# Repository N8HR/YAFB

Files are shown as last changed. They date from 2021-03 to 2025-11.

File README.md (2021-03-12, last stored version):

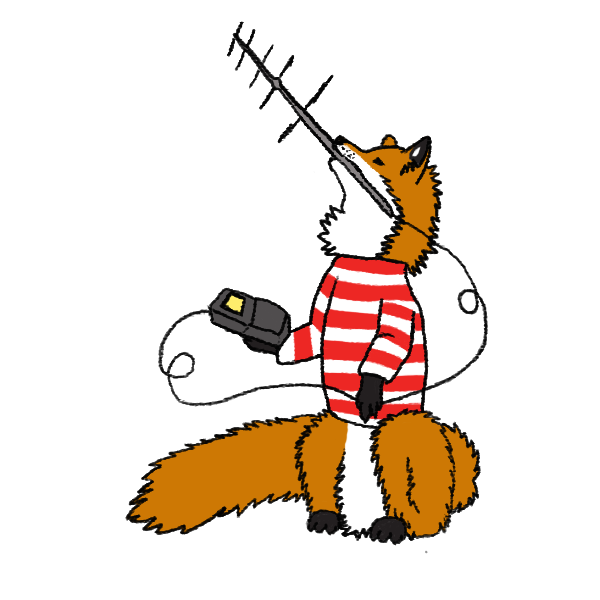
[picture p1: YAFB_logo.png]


# Yet Another Foxbox (YAFB)
YAFB is an amateur radio fox transmitter designed for an ESP32-S2-Saola-1 and a NiceRF SA818.

Still being worked on and is not in a functional state but there is a cool logo to look at!

My goal is to provide a way to make a cheap alternative fox transmitter. When done you'll be provided with all the files needed to make your own.

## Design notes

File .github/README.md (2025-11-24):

> [!Note]
> This is a project that doesn't get enough of my time and is never complete.  
> If you want an actual product that just works and is based off of this project, see https://github.com/c0ldbru/fox

# Yet Another Foxbox (YAFB)



YAFB is an amateur radio fox transmitter designed for an ESP32-S2-Saola-1 and a NiceRF SA818.

Still being worked on and now works fairly well on my bench. Hasn't been tested yet in the field.
As of Nov 2023 just sent in to have v4.1 of the board to be made. More updates soon.

I started this because I was too cheap to buy one and I had way too much time on my hands. And I kind of am enjoying it. Weird. 

My goal is to provide a way to make a cheap alternative fox transmitter. When done you'll be provided with all the files needed to make your own.

## Features
* 1W VHF or UHF transmitter (NiceRF SA818)
* Configure it over Bluetooth

## PCB
|Front|Back|
|:-:|:-:|
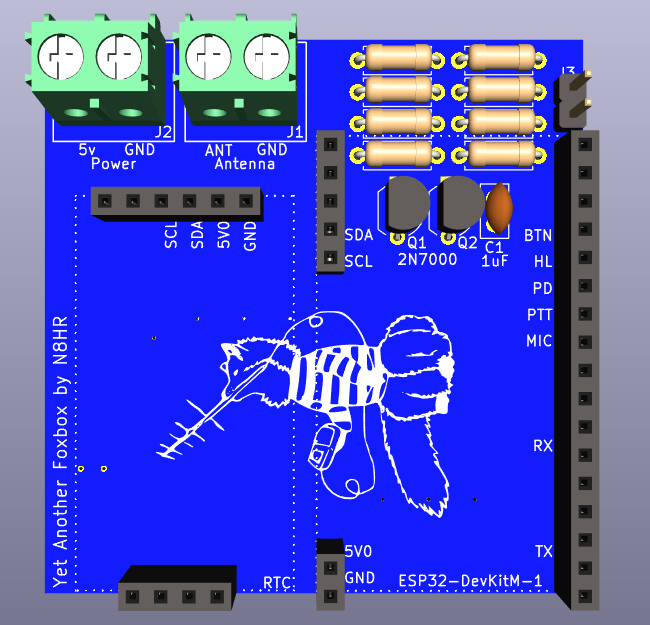
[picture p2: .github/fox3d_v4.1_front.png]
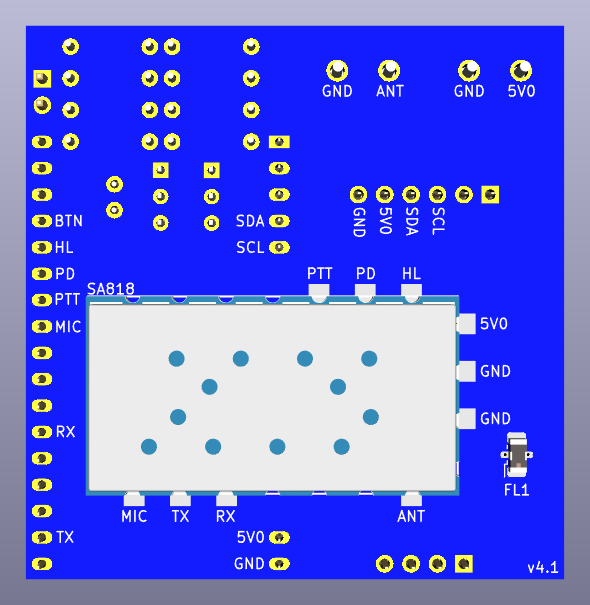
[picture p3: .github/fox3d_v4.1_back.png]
|||

## Parts
* 1x ESP32-S2-Saola-1R Dev Board (Microcontroller)
* 1x NiceRF SA818(S) (Transmitter)
* 1x DS3231 RTC Module (Real Time Clock)
* 1x Mini-Circuits LFCN-160+ (Low Pass Filter)
* 3x 10k Resistors
* 1x 3.3k Resistor
* 1x 1.8k Resistor
* 1x 1k Resistor
* 2x 150 Resistor
* 1x 1uF Capacitor
* 2x 2N7000 Transistor
* 2x TB002-500-02BE Terminal Blocks
* Male and Female Header Connectors
* 5v Power Source
* Optional Push Button

## Licenses
* The hardware side of this project uses the CERN Open Hardware Licence Version 2 - Weakly Reciprocal (CERN-OHL-W-2.0)
* The software side of this project uses the GNU General Public License v3.0 or later (GPL-3.0-or-later)

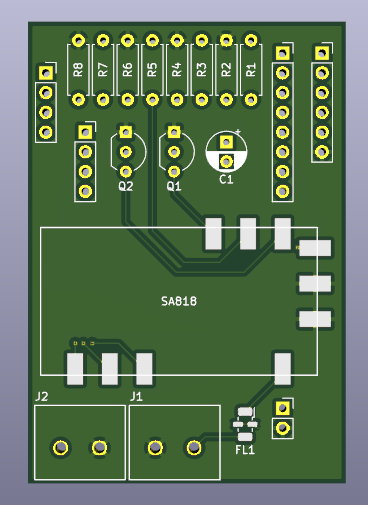
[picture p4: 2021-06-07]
.github/fox3d_front.png

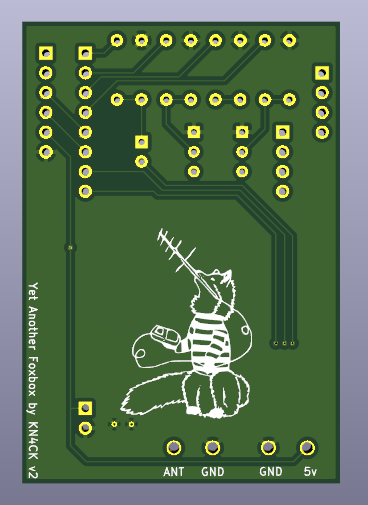
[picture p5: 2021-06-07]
.github/fox3d_back.png

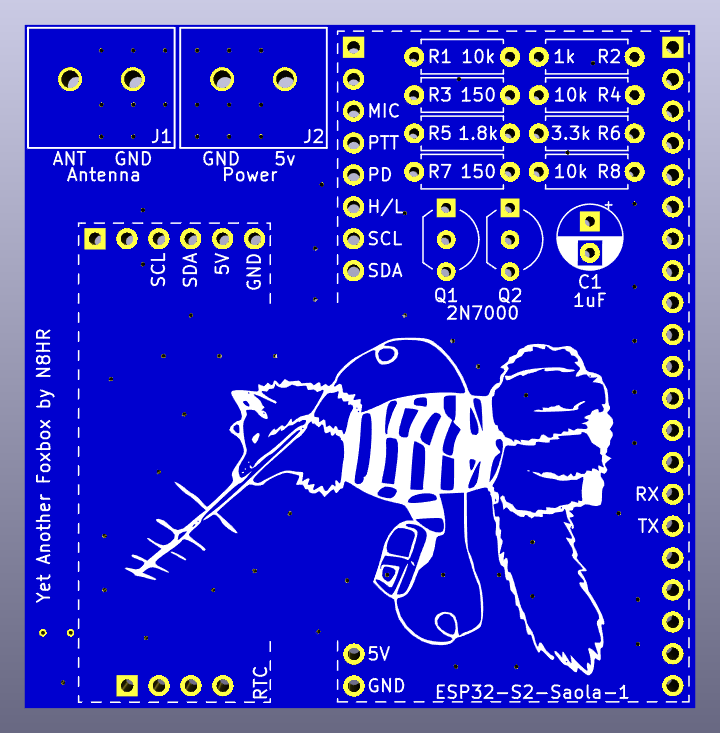
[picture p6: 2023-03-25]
.github/fox3d_v3_front.png

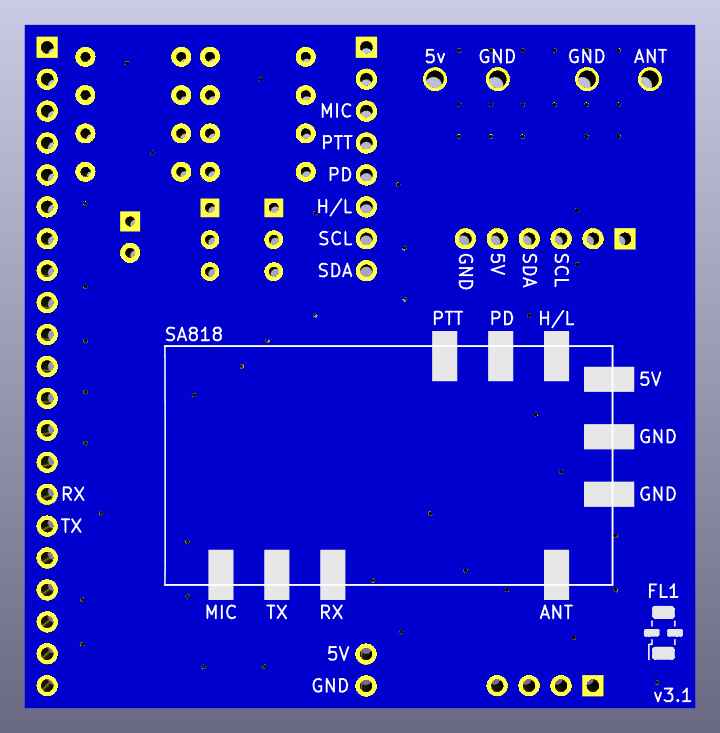
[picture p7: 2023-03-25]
.github/fox3d_v3_back.png

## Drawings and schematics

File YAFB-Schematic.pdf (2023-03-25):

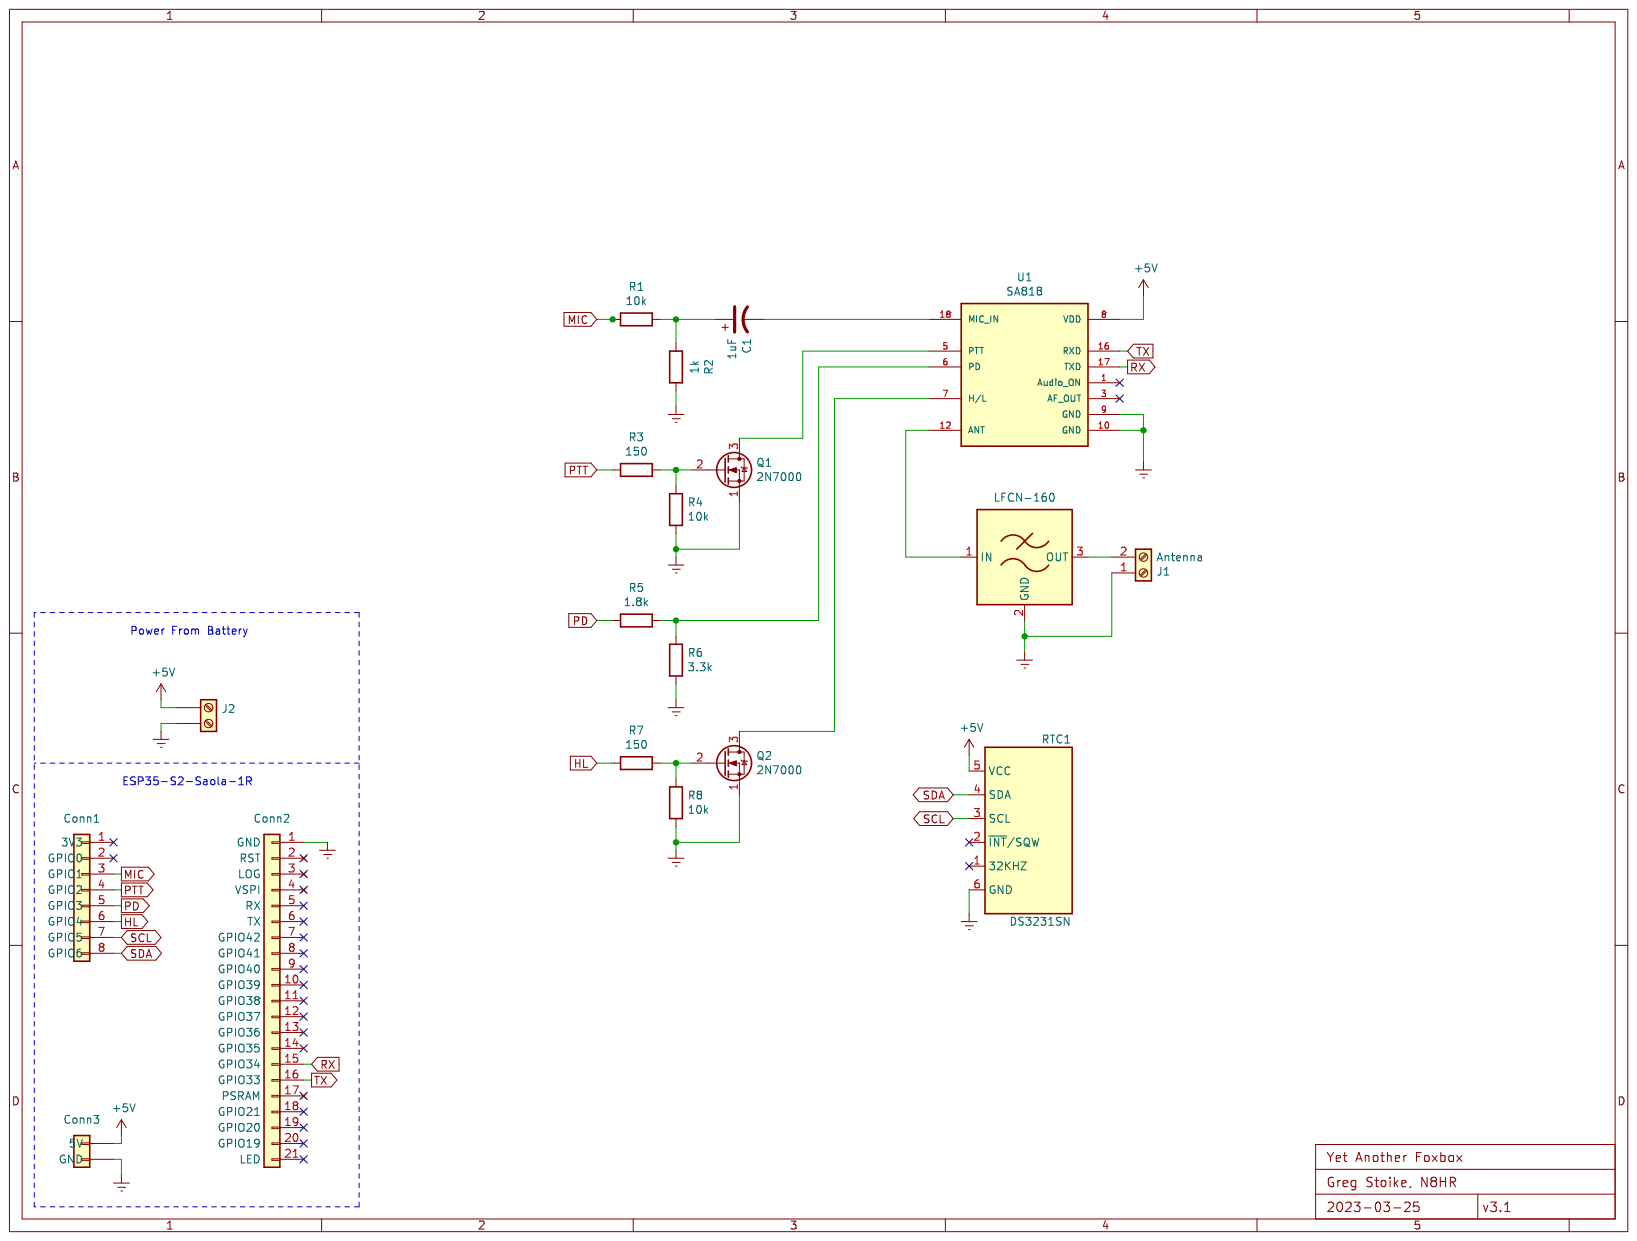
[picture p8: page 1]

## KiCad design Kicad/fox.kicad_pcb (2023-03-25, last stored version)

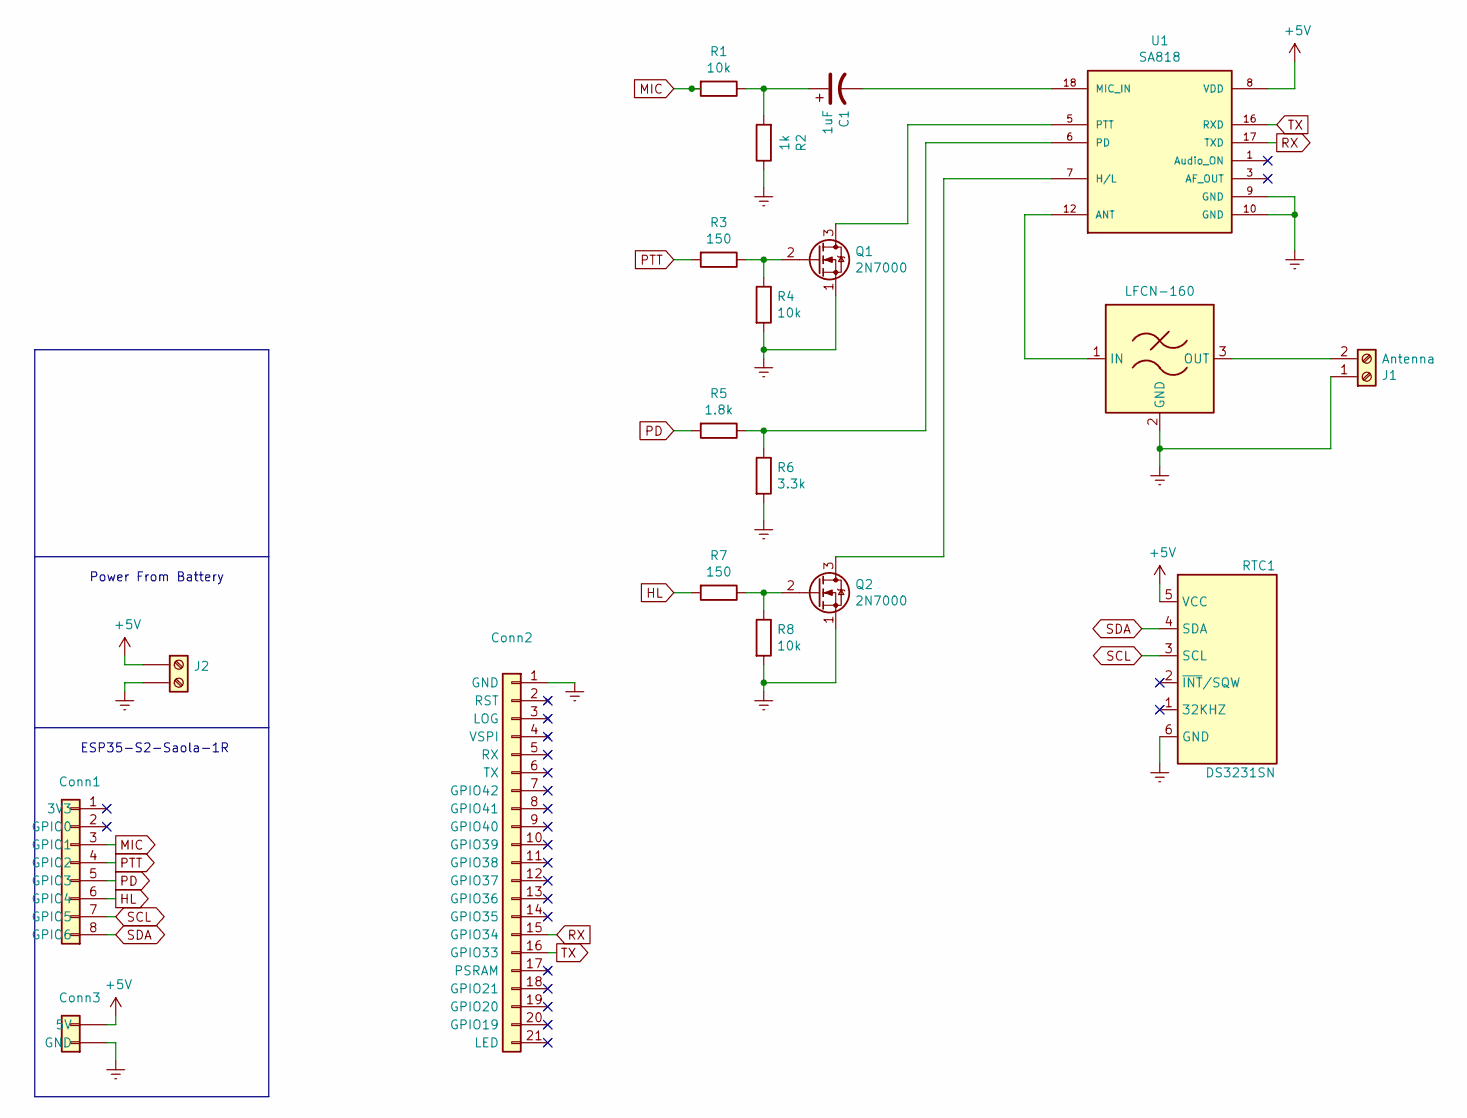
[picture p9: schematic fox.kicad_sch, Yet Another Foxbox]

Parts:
C1: 1uF; CP_Radial_D5.0mm_P2.50mm
Conn1: ESP32-S2-Saola-1R_GPIO_1; PinSocket_1x08_P2.54mm_Vertical
Conn2: ESP32-S2-Saola-1R_GPIO_2; PinSocket_1x21_P2.54mm_Vertical
Conn3: ESP32-S2-Saola-1R_Power; PinSocket_1x02_P2.54mm_Vertical
FL1: LFCN-160; Filter_Mini-Circuits_FV1206
J1: Antenna; OSTTA020161
J2: Power; OSTTA020161
Q1, Q2: 2N7000; TO-92_Inline_Wide
R1, R4, R8: 10k; R_Axial_DIN0207_L6.3mm_D2.5mm_P7.62mm_Horizontal
R2: 1k; R_Axial_DIN0207_L6.3mm_D2.5mm_P7.62mm_Horizontal
R3, R7: 150; R_Axial_DIN0207_L6.3mm_D2.5mm_P7.62mm_Horizontal
R5: 1.8k; R_Axial_DIN0207_L6.3mm_D2.5mm_P7.62mm_Horizontal
R6: 3.3k; R_Axial_DIN0207_L6.3mm_D2.5mm_P7.62mm_Horizontal
RTC1: DS3231SN
U1: SA818; DRA818; PART_REV 1.23

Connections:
+5V: Conn3.5v0 (5V), J2.1, RTC1.5 (VCC), U1.8 (VDD)
GNDREF: Conn2.1 (GND), Conn3.GND, FL1.2 (GND), FL1.4 (GND), J1.1, J2.2, Q1.1 (S), Q2.1 (S), R2.1, R4.2, R6.2, R8.2, RTC1.6 (GND), U1.9 (GND), U1.10 (GND)
HL: Conn1.6 (GPIO4), R7.2
MIC: Conn1.3 (GPIO1), R1.2
unnamed: C1.1, R1.1, R2.2
unnamed: C1.2, U1.18 (MIC_IN)
unnamed: FL1.1 (IN), U1.12 (ANT)
unnamed: FL1.3 (OUT), J1.2
unnamed: Q1.2 (G), R3.1, R4.1
unnamed: Q1.3 (D), U1.5 (PTT)
unnamed: Q2.2 (G), R7.1, R8.1
unnamed: Q2.3 (D), U1.7 (H/L)
unnamed: R5.1, R6.1, U1.6 (PD)
PD: Conn1.5 (GPIO3), R5.2
PTT: Conn1.4 (GPIO2), R3.2
RX: Conn2.15 (GPIO34), U1.17 (TXD)
SCL: Conn1.7 (GPIO5), RTC1.3 (SCL)
SDA: Conn1.8 (GPIO6), RTC1.4 (SDA)
TX: Conn2.16 (GPIO33), U1.16 (RXD)

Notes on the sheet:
ESP35-S2-Saola-1R
Power From Battery

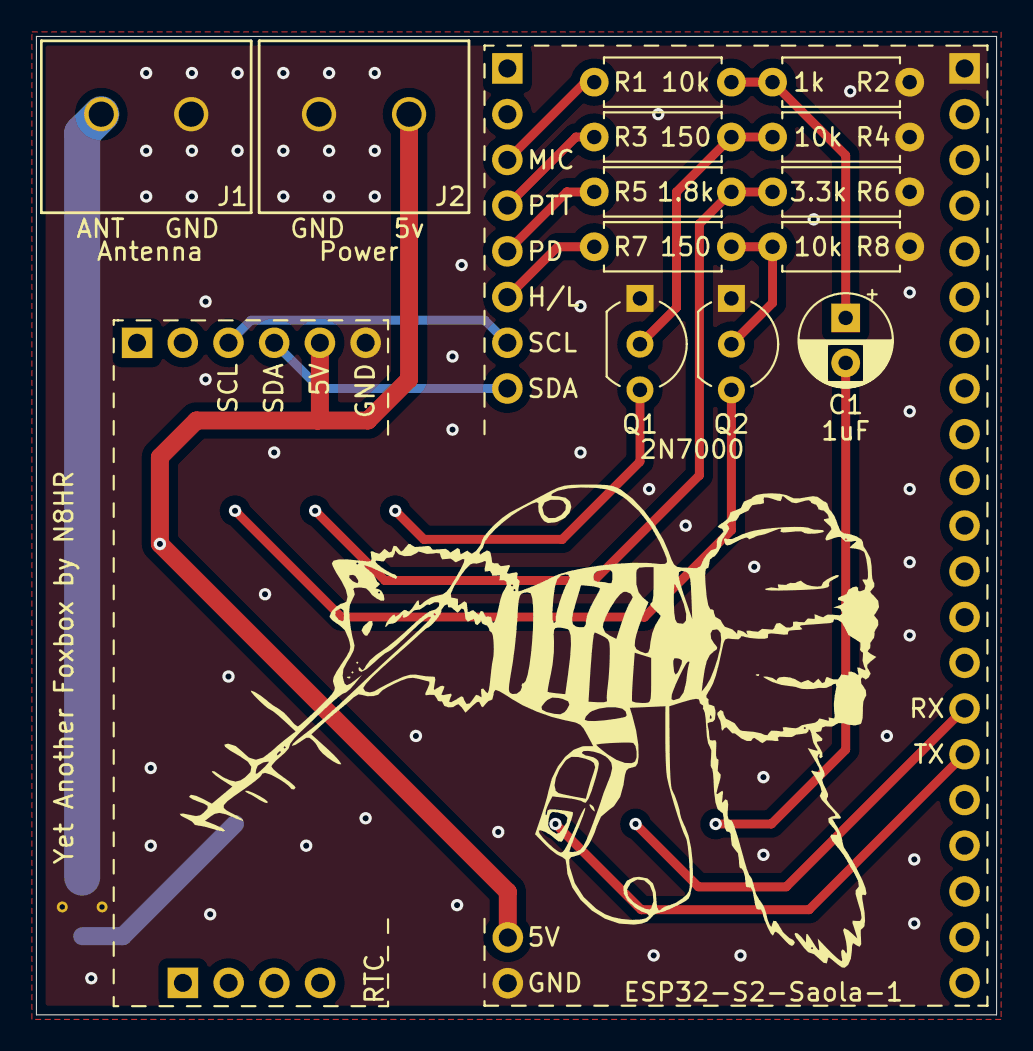
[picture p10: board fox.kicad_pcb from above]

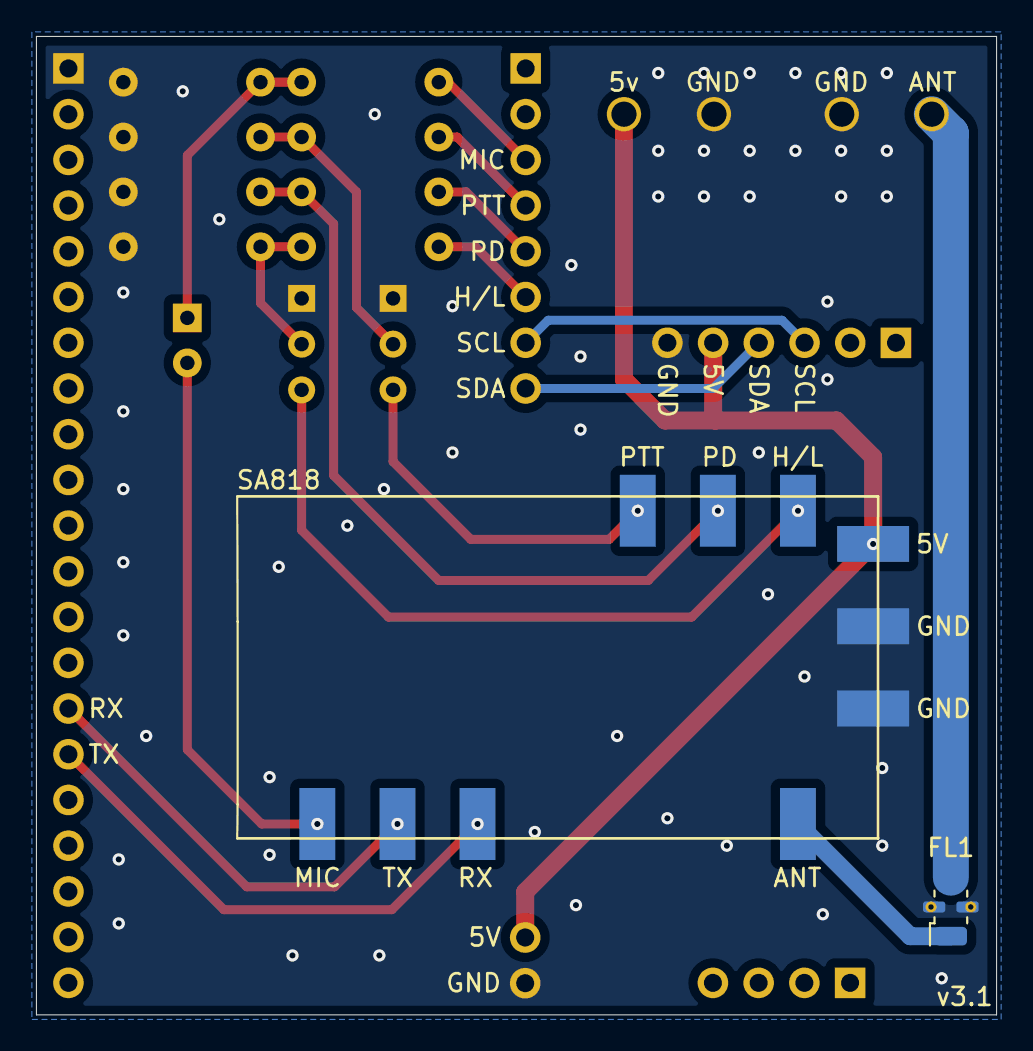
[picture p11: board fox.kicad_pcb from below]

Board: 2 copper layers, 53.3 x 54.4 mm, 19 parts (2 on the bottom side), 19 nets.

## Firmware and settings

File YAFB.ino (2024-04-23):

/*
 *   This file is part of Yet Another Foxbox (YAFB).
 *   
 *   Yet Another Foxbox (YAFB) is an amateur radio fox transmitter 
 *   designed for an ESP32-DevKitM-1 and a NiceRF SA818.
 *   
 *   Copyright (c) 2021-2023 Gregory Stoike (N8HR).
 *   
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
 */


/****************************************************************************** 
 *   Todo:
 *   
 *   General
 *    * Implement Start/Stop time function
 *    *
 ******************************************************************************/


#include <Preferences.h>        // For storing variables that survive a reset
#include "RTClib.h"             // For DS3231 RTC Module
#include <Wire.h>               // For I2C Communication (DS3231)

// Preferences Settings
Preferences preferences;

// Declare some initial variables
//  This is needed due to AsyncWebServer needing them before we can pull them from memory
//  So we declare these and change them in setup via preferences if set
String callmessage = "N0CALL Fox";
String morse = "-. ----- -.-. .- .-.. .-.. / ..-. --- -..-";
int timebetween = 57000; // Time between transmissions in miliseconds (1 sec = 1000 miliseconds)
boolean onoff = false; // false = off, true = on
struct tm tmcurrenttime = {0};
struct tm tmstarttime = {0};
struct tm tmendtime = {0};
float txfrequency = 146.565; // 146.565 is the normal TX frequency for foxes
float rxfrequency = 146.565; // RX frequency
byte bandwidth = 1; // Bandwidth, 0=12.5k, 1=25K
byte squelch = 1; // Squelch 0-8, 0 is listen/open
byte volume = 5; // Volume 1-8

// ESP32-S2 Settings
#define PTT_Pin 2 
#define PD_Pin 3
#define HL_Pin 4
#define SCL_Pin 5
#define SDA_Pin 6
#define SATX_Pin 33
#define SARX_Pin 34

// DS3231 Settings
RTC_DS3231 rtc;

// Misc Variables
unsigned long oneminmillis = 10000000;
unsigned long tenminmillis = 1000000;
unsigned long radiomillis = 1000000;
unsigned long tempmillis = 1000000;
boolean updateSAsettingsFlag = false;

HardwareSerial SASerial(1);

/****************************************************************************** 
 * Standard Setup Function
 ******************************************************************************/
void setup() 
{
  // Start Serial for debugging
  Serial.begin(115200); // Serial for ESP32-S2 board
  SASerial.begin(9600, SERIAL_8N1, SARX_Pin, SATX_Pin); // Serial for SA818 using pins GPIO5 (rx) & GPIO6 (tx)
  delay(1000);
    
  // Replace fox settings from memory
  preferences.begin("settings", true);
    timebetween = preferences.getInt("timebetween", 60000);
    onoff = preferences.getBool("onoff", false);
    txfrequency = preferences.getFloat("txfrequency", 146.565);
    rxfrequency = preferences.getFloat("rxfrequency", 146.565);
    bandwidth = preferences.getChar("bandwidth", 1);
    squelch = preferences.getChar("squelch", 1);
    volume = preferences.getChar("volume", 5);
    
    time_t starttemp = preferences.getULong("starttime", 500001720);
    localtime_r(&starttemp, &tmstarttime);
    
    time_t endtemp = preferences.getULong("endtime", 1704067200);
    localtime_r(&endtemp, &tmendtime);

    callmessage = preferences.getString("callmessage", "N0CALL Fox");
    morse = preferences.getString("morse", "-. ----- -.-. .- .-.. .-.. / ..-. --- -..-");
  preferences.end();
  
  // Set pins
  pinMode(PTT_Pin, OUTPUT);
  pinMode(PD_Pin, OUTPUT);
  pinMode(HL_Pin, OUTPUT);
  digitalWrite(PTT_Pin, LOW); // LOW is RX, High is TX, it's confusing??
  digitalWrite(PD_Pin, LOW); // LOW for power down mode, HIGH for normal mode??
  digitalWrite(HL_Pin, LOW); // LOW for .5w, HIGH for 1w??
  
  // Start the I2C interface
  Wire.begin(SDA_Pin, SCL_Pin);

/*  
    Stored for later use

    preferences.putBool("onoff", onoff);
    preferences.putBool("onoff", onoff);
    preferences.putString("callmessage", callmessage);
    preferences.putString("morse", morse);
    preferences.putFloat("txfrequency", txfrequency);
    preferences.putFloat("rxfrequency", rxfrequency);
    preferences.putChar("bandwidth", bandwidth);
    preferences.putChar("volume", volume);
    preferences.putChar("squelch", squelch);
    preferences.putChar("timebetween", timebetween);
    preferences.putULong("starttime", temp);
    preferences.putULong("endtime", temp);
*/

  // Set RTC time if needed
  if (! rtc.begin()) {
    Serial.println("Couldn't find RTC");
  }

  // If power was lost, set it to the compiled date & time. About 30-40sec slow?
  if (rtc.lostPower()) {
    Serial.println("RTC lost power, let's set the time!");
    rtc.adjust(DateTime(F(__DATE__), F(__TIME__))); 
  }
  
  updateSysTime();
  updateSAsettings();

}

/****************************************************************************** 
 * Standard Loop Function
 * 
 * Periodically update the ESP32 time from the RTC
 * Play the audio melody then play the identification in morse code then wait
 ******************************************************************************/
void loop()
{
// Runs updateSysTime() every 10 minutes to keep the ESP32 in sync with the RTC in case of drift
  unsigned long currentMillis = millis();
  if(currentMillis - tenminmillis >= 600000)
  {
    tenminmillis = currentMillis;   
    updateSysTime();
  }

  // Starts transmitting with a time gap of 'timebetween' && if 'onoff' is set to true
  currentMillis = millis();
  if(currentMillis - radiomillis >= timebetween && onoff)
  {
    digitalWrite(HL_Pin, HIGH); // HIGH for .5w, LOW for 1w??

    // Set pins to be ready for transmit
    digitalWrite(PD_Pin, HIGH); // Take the SA818 out of PD state
    digitalWrite(PTT_Pin, HIGH); // Put the SA818 in TX mode
    delay(3000);  // Takes about 3 seconds for SA818 to come out of PD state

    // Play the song
    playMelody();
    delay(700); // Just a slight break between
    // Play the ID in morse
    playMorse();

    // Set pins to stop transmit and power down the SA818 for power saving
    digitalWrite(PTT_Pin, LOW); // Put the SA818 in RX mode
    digitalWrite(PD_Pin, LOW); // Put the SA818 back into PD state
    // End Transmittion Block

    // Set for gap between tranmissions
    radiomillis = millis();
  }
 
  currentMillis = millis();
  if(currentMillis - tempmillis >= 1000)
  {
    String content = "";  //null string constant ( an empty string )
    char character;
    while(SASerial.available()) 
    {
      character = SASerial.read();
      content.concat(character);
      content.trim();
    }
    if (content != "") 
    {
      Serial.println("***SA818**********************************************************************");
      Serial.print("Response: ");
      Serial.println(content);
      Serial.println("******************************************************************************");
      Serial.println();
    }
    
    tempmillis = currentMillis;
  }

  if (updateSAsettingsFlag)
  {
    updateSAsettingsFlag = false;
    updateSAsettings();

  }
}

/****************************************************************************** 
 * Misc Time Functions
 * 
 * updateSysTime
 *    Updates the ESP32 sytem time using the external RTC
 ******************************************************************************/

void updateSysTime()
{  
  // Update the system time from RTC time
  DateTime now = rtc.now();
  struct timeval tv{ .tv_sec = now.unixtime() };
  settimeofday(&tv, NULL);
  getLocalTime(&tmcurrenttime);
  
  Serial.println("***updateSysTime**************************************************************");
  Serial.println("Synced the ESP32 time from the RTC time.");
  Serial.print("\tCurrent time: ");
  Serial.println(&tmcurrenttime, "%B %d %Y %H:%M:%S");
  Serial.println("******************************************************************************");
  Serial.println();
}

/****************************************************************************** 
 * These functions are for the SA818
 * 
 * SA818Connect
 *    Used for initial handshake with the SA818
 * 
 * SA818SetGroup
 *    Sets the Bandwidth, TX Frequency, RX Frequency, CTCSS tones, and Squelch
 * 
 * SA818SetVolume 
 *    Sets the output volume of the SA818
 * 
 * SA818SetFilter
 *    Sets the filters of the SA818
 * 
 * SA818SetTail
 *    Sets what kind of tail you want after tx
 ******************************************************************************/

void updateSAsettings(void)
{
  SA818SetGroup();
}

void SA818Connect(void)
{
  char rxbuffer[20];  // buffer for response string
  byte rxlen=0;   // counter for received bytes
  do
  {
    SASerial.println("AT+DMOCONNECT");         // begin message
    rxlen=SASerial.readBytesUntil('\n',rxbuffer,19);
  } while(rxlen==0);    // send command until answer is received
  rxbuffer[rxlen-1]=0;  // check length of answer and remove cr character
  rxbuffer[rxlen]=0; // remove last byte and end string
  delay(1000);    // wait a little bit
}

void SA818SetGroup()
{
  digitalWrite(PD_Pin, HIGH); // LOW for power down mode, HIGH for normal mode
  digitalWrite(PTT_Pin, LOW); // LOW is RX, High is TX
  delay(3000);  // Takes about 3 seconds for SA818 to come out of PD state

  SA818Connect();
  preferences.begin("settings", true);
    txfrequency = preferences.getFloat("txfrequency");
    rxfrequency = preferences.getFloat("rxfrequency");
    bandwidth = preferences.getChar("bandwidth");
    squelch = preferences.getChar("squelch");
  preferences.end();
  byte txctcss = 0;
  byte rxctcss = 0;
  
  SASerial.print("AT+DMOSETGROUP=");
  SASerial.print(bandwidth);
  SASerial.print(",");
  SASerial.print(txfrequency, 4);
  SASerial.print(",");
  SASerial.print(rxfrequency, 4);
  SASerial.print(",00");
  if(txctcss<10) SASerial.print("0");
  SASerial.print(txctcss);
  SASerial.print(",");    
  SASerial.print(squelch);
  SASerial.print(",00");
  if(rxctcss<10) SASerial.print("0");
  SASerial.println(txctcss);
  delay(1000);
  digitalWrite(PD_Pin, LOW); // Put the SA818 back into PD state
}

/*
void SA818SetVolume()
{
  digitalWrite(PD_Pin, HIGH); // LOW for power down mode, HIGH for normal mode
  digitalWrite(PTT_Pin, LOW); // LOW is RX, High is TX
  delay(3000);  // Takes about 3 seconds for SA818 to come out of PD state
  
  SA818Connect();
  preferences.begin("settings", true);
    volume = preferences.getChar("volume", 5);
  preferences.end();
  SASerial.print("AT+DMOSETVOLUME=");
  SASerial.println(volume);
  digitalWrite(PD_Pin, LOW); // Put the SA818 back into PD state
}

void SA818SetFilter(byte prefilter, byte highpassfilter, byte lowpassfilter)
{
  SA818Connect();
  SASerial.print("AT+SETFILTER=");
  SASerial.print(prefilter);
  SASerial.print(",");
  SASerial.print(highpassfilter);
  SASerial.print(",");
  SASerial.println(lowpassfilter);
}

void SA818SetTail(byte tailtone)
{
  SA818Connect();
  SASerial.print("AT+SETTAIL=");
  SASerial.println(tailtone);
}
*/

/****************************************************************************** 
 * These functions are for debugging or displaying info
 * 
 * printVars
 *    Prints out the variables and their values
 *    
 * printTimes
 *    Outputs various times: System time, Unix time, RTC time   
 ******************************************************************************/


void printVars()
{
  Serial.println("***printVars******************************************************************");
  Serial.print("Call: ");
  Serial.println(callmessage);
  Serial.print("Morse: ");
  Serial.println(morse);
  Serial.print("Time Between: ");
  Serial.println(timebetween);
  Serial.print("OnOff: ");
  Serial.println(onoff);
  Serial.print("TX: ");
  Serial.println(txfrequency, 3);
  /*
   * Serial.print("RX: ");  
   * Serial.println(rxfrequency, 3);
   * Serial.print("Bandwidth: ");
   * Serial.println(bandwidth);
   * Serial.print("Squelch: ");
   * Serial.println(squelch);  
   * Serial.print("Volume: ");  
   * Serial.println(volume);
  */
  Serial.print("Current: ");
  Serial.println(&tmcurrenttime, "%B %d %Y %H:%M:%S");
  Serial.print("Start: ");
  Serial.println(&tmstarttime, "%B %d %Y %H:%M:%S");
  Serial.print("End: ");
  Serial.println(&tmendtime, "%B %d %Y %H:%M:%S");
  Serial.println("******************************************************************************");
  Serial.println();
}

void printTimes()
{
  Serial.println("***printTimes*****************************************************************");

  if(!getLocalTime(&tmcurrenttime)){
    Serial.println("Failed to obtain time");
    return;
  }

  Serial.print("Systime: ");
  Serial.println(&tmcurrenttime, "%B %d %Y %H:%M:%S");
  //  Serial.print("Starttime: ");
  //  Serial.println(&tmstarttime, "%B %d %Y %H:%M:%S");
  //  Serial.print("Endtime: ");
  //  Serial.println(&tmendtime, "%B %d %Y %H:%M:%S");

  DateTime now = rtc.now();
  //  Serial.print("Unix: ");
  //  Serial.println(now.unixtime());
  
  Serial.print("RTC: ");    
  Serial.printf("%02d/%02d/%04d (%02d:%02d:%02d)\n", now.month(), now.day(), now.year(), now.hour(), now.minute(), now.second());
  Serial.println("******************************************************************************");
  Serial.println();
}

void printTemp()
{
    Serial.println("***Temperature****************************************************************");
    Serial.print(rtc.getTemperature());
    Serial.println(" C");
    Serial.print(rtc.getTemperature()*1.8+32);
    Serial.println(" F");
    Serial.println("******************************************************************************");
    Serial.println();
}

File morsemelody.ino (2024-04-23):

/*
 *   This file is part of Yet Another Foxbox (YAFB).
 *   
 *   Yet Another Foxbox (YAFB) is an amateur radio fox transmitter 
 *   designed for an ESP32-DevKitM-1 and a NiceRF SA818.
 *   
 *   Copyright (c) 2021-2023 Gregory Stoike (N8HR).
 *   
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
 */

// ESP32-S2 Settings
#define Sound_Pin 1

// ledc Settings
int ledc_freq = 2000;
int ledc_channel = 0;
int ledc_resolution = 8;

// Notes and Frequencies
#define REST 0
#define NOTE_B0  31
#define NOTE_C1  33
#define NOTE_CS1 35
#define NOTE_D1  37
#define NOTE_DS1 39
#define NOTE_E1  41
#define NOTE_F1  44
#define NOTE_FS1 46
#define NOTE_G1  49
#define NOTE_GS1 52
#define NOTE_A1  55
#define NOTE_AS1 58
#define NOTE_B1  62
#define NOTE_C2  65
#define NOTE_CS2 69
#define NOTE_D2  73
#define NOTE_DS2 78
#define NOTE_E2  82
#define NOTE_F2  87
#define NOTE_FS2 93
#define NOTE_G2  98
#define NOTE_GS2 104
#define NOTE_A2  110
#define NOTE_AS2 117
#define NOTE_B2  123
#define NOTE_C3  131
#define NOTE_CS3 139
#define NOTE_D3  147
#define NOTE_DS3 156
#define NOTE_E3  165
#define NOTE_F3  175
#define NOTE_FS3 185
#define NOTE_G3  196
#define NOTE_GS3 208
#define NOTE_A3  220
#define NOTE_AS3 233
#define NOTE_B3  247
#define NOTE_C4  262
#define NOTE_CS4 277
#define NOTE_D4  294
#define NOTE_DS4 311
#define NOTE_E4  330
#define NOTE_F4  349
#define NOTE_FS4 370
#define NOTE_G4  392
#define NOTE_GS4 415
#define NOTE_A4  440
#define NOTE_AS4 466
#define NOTE_B4  494
#define NOTE_C5  523
#define NOTE_CS5 554
#define NOTE_D5  587
#define NOTE_DS5 622
#define NOTE_E5  659
#define NOTE_F5  698
#define NOTE_FS5 740
#define NOTE_G5  784
#define NOTE_GS5 831
#define NOTE_A5  880
#define NOTE_AS5 932
#define NOTE_B5  988
#define NOTE_C6  1047
#define NOTE_CS6 1109
#define NOTE_D6  1175
#define NOTE_DS6 1245
#define NOTE_E6  1319
#define NOTE_F6  1397
#define NOTE_FS6 1480
#define NOTE_G6  1568
#define NOTE_GS6 1661
#define NOTE_A6  1760
#define NOTE_AS6 1865
#define NOTE_B6  1976
#define NOTE_C7  2093
#define NOTE_CS7 2217
#define NOTE_D7  2349
#define NOTE_DS7 2489
#define NOTE_E7  2637
#define NOTE_F7  2794
#define NOTE_FS7 2960
#define NOTE_G7  3136
#define NOTE_GS7 3322
#define NOTE_A7  3520
#define NOTE_AS7 3729
#define NOTE_B7  3951
#define NOTE_C8  4186
#define NOTE_CS8 4435
#define NOTE_D8  4699
#define NOTE_DS8 4978


/****************************************************************************** 
 * Morse and Audio Playing Functions
 * 
 * playMelody
 *    Plays a small melody
 *    
 * playMorse
 *    Plays 'callsign' in morse code
 *    
 * createMorse
 *    Converts 'callmessage' into a morse code language
 ******************************************************************************/
 
 /****************************************************************************** 
 * The playMelody fuction was adpated from:
 * https://github.com/robsoncouto/arduino-songs
 *                                                 
 * From https://github.com/robsoncouto/arduino-songs/blob/master/README.md
 *  Commit 8fb1283 on Feb 13, 2019 
 *  
 *    Copyright
 * 
 *    Every sketch here has been written by myself, although based on 
 *    scores I found online or books I own. These scores are linked in 
 *    each file when possible. You can use the sketches for anything, 
 *    I only kindly ask that you give credit if you use these codes on 
 *    a tutorial, video, example, etc.
 ******************************************************************************/

void playMelody() 
{
  // Change this to make the song slower or faster
  int tempo = 140;
  
  // Notes of the moledy followed by the duration
  // A 4 means a quarter note, 8 an eighteenth , 16 sixteenth, so on
  // Negative numbers are used to represent dotted notes,
  //  so -4 means a dotted quarter note, that is, a quarter plus an eighteenth!!
  int melody[] = 
  {
    // LOW
    NOTE_A4,8,  NOTE_A4,8,  NOTE_E4,8, NOTE_E4,8, NOTE_C4,8,  NOTE_C4,8,  NOTE_E4,8, NOTE_E4,8, 
    NOTE_A4,8,  NOTE_A4,8,  NOTE_E4,8, NOTE_E4,8, NOTE_C4,8,  NOTE_C4,8,  NOTE_E4,8, NOTE_E4,8, 

    // HIGH
    NOTE_A5,8,  NOTE_A5,8,  NOTE_E5,8, NOTE_E5,8, NOTE_C5,8,  NOTE_C5,8,  NOTE_E5,8, NOTE_E5,8, 
    NOTE_A5,8,  NOTE_A5,8,  NOTE_E5,8, NOTE_E5,8, NOTE_C5,8,  NOTE_C5,8,  NOTE_E5,8, NOTE_E5,8, 

    // MEDIUM
    NOTE_C4,8,  NOTE_C4,8,  NOTE_A5,8, NOTE_A5,8, NOTE_E4,8,  NOTE_E4,8,  NOTE_A5,8, NOTE_A5,8, 
    NOTE_C4,8,  NOTE_C4,8,  NOTE_A5,8, NOTE_A5,8, NOTE_E4,8,  NOTE_E4,8,  NOTE_A5,8, NOTE_A5,8, 

    // HIGH
    NOTE_A5,8,  NOTE_A5,8,  NOTE_E5,8, NOTE_E5,8, NOTE_C5,8,  NOTE_C5,8,  NOTE_E5,8, NOTE_E5,8, 
    NOTE_A5,8,  NOTE_A5,8,  NOTE_E5,8, NOTE_E5,8, NOTE_C5,8,  NOTE_C5,8,  NOTE_E5,8, NOTE_E5,8, 

    // LOW
    NOTE_A4,4, NOTE_E4,4, NOTE_C4,8, NOTE_E4,4, 
    NOTE_A4,4, NOTE_E4,4, NOTE_C4,8, NOTE_E4,4, 
  };
  
  // sizeof gives the number of bytes, each int value is composed of two bytes (16 bits)
  // There are two values per note (pitch and duration), so for each note there are four bytes
  int notes = sizeof(melody) / sizeof(melody[0]) / 2;
  
  // This calculates the duration of a whole note in ms (60s/tempo)*4 beats
  int wholenote = (60000 * 4) / tempo;
  
  int divider = 0, noteDuration = 0;

  ledcSetup(ledc_channel, ledc_freq, ledc_resolution);
  ledcAttachPin(Sound_Pin, ledc_channel);

  Serial.println("Playing melody start");
  // Iterate over the notes of the melody.
  // Remember, the array is twice the number of notes (notes + durations)
  for (int thisNote = 0; thisNote < notes * 2; thisNote = thisNote + 2) 
  {
    // calculates the duration of each note
    divider = melody[thisNote + 1];
    if (divider > 0) {
      // Regular note, just proceed
      noteDuration = (wholenote) / divider;
    } else if (divider < 0) {
      // Dotted notes are represented with negative durations
      noteDuration = (wholenote) / abs(divider);
      noteDuration *= 1.5; // increases the duration in half for dotted notes
    }

    // We only play the note for 90% of the duration, leaving 10% as a pause
    // In my testing with the ESP32-S2-Saola-1 I noticed frequency was off by a
    //  factor of 80, so I correct that here. YMMV
    ledcWriteTone(ledc_channel, melody[thisNote] * 80);
    delay(noteDuration * 0.9);
    ledcWriteTone(ledc_channel, 0);
    delay(noteDuration * 0.1);
  }
  Serial.println("Playing melody end");
  ledcDetachPin(Sound_Pin);
}

/****************************************************************************** 
 * Morse Generating Function
 * 
 *  Input: Yet Another Foxbox
 *  Output: -.-- . - / .- -. --- - .... . .-. / ..-. --- -..- -... --- -..-
 ******************************************************************************/
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

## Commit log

2021-02-25 in onTimer() changed DacPin from 25,26 (esp32) to 17,18 (esp32-s2)
2023-03-05 Add files via upload
    v3 of the PCB
2023-03-25 Added v3.1
    [fox.kicad_pcb, fox.kicad_sch, fox.sch]
2023-03-25 Made it prettier
    [fox.kicad_sch]

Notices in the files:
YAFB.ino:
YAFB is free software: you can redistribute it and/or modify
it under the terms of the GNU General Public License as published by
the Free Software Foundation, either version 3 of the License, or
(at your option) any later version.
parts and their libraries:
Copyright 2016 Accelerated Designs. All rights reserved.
